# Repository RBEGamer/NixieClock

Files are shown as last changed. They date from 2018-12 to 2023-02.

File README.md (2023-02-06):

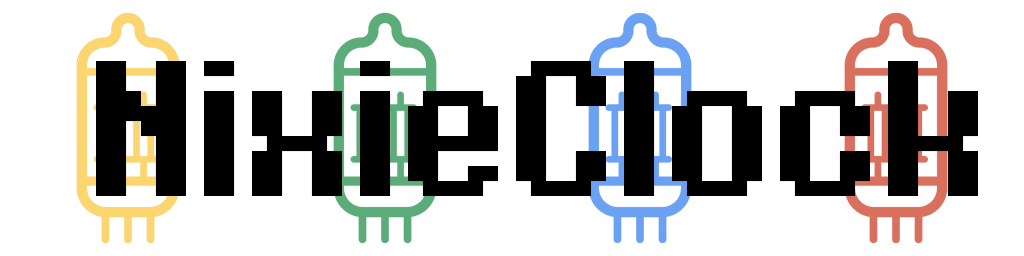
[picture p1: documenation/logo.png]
Gopher image


# A IN-16/IN-8 based nixie clock with WIFI

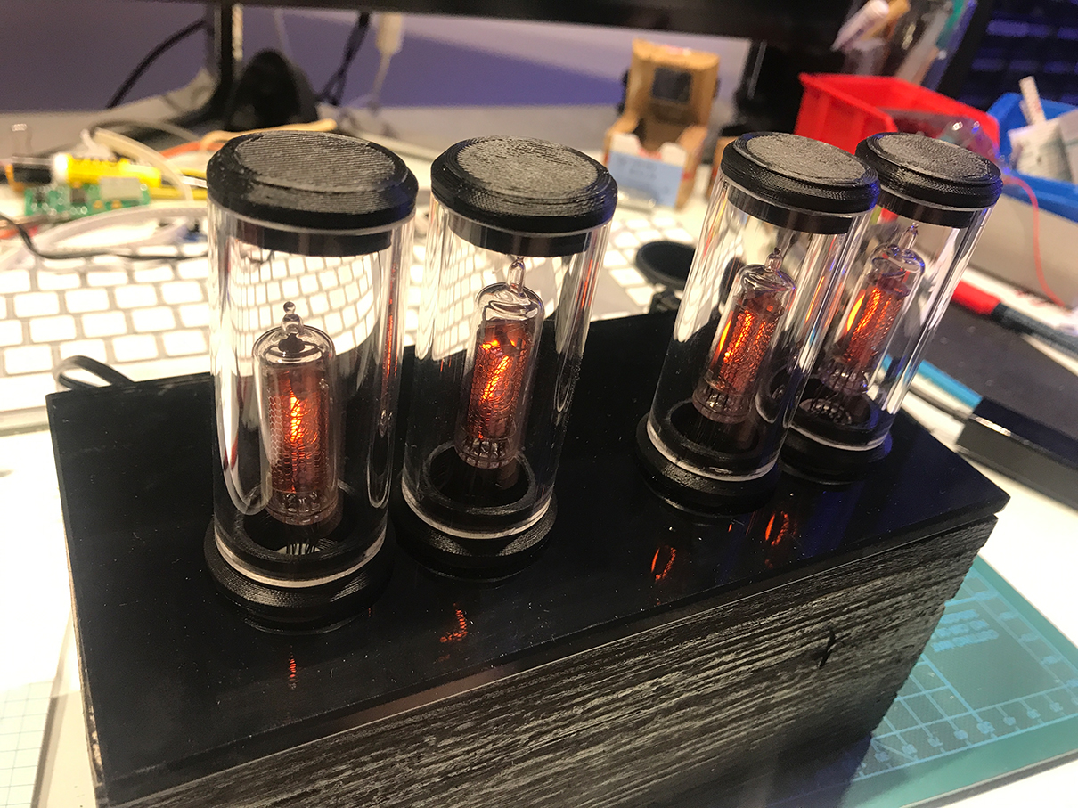
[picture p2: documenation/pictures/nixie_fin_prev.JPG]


# FEATURES
* burn out protection (cycle all numbers for 10 seconds every 10minutes)
* in8 or in16 tube usable via adapter pcbs
* for 4 (hours:mins) or 6 tubes (hours:mins:secs)
* easy to expand
* simple schematic using THT parts only
* tube holders with simple mount for easy replacement

## [OPTIONAL] FEATURES WIFI EXTENTION
* using esp8266 to add wifi support
* NTP SYNC
* CAPTIVE PORTAL to set wifi settings
* set timezone
* start antiburn-in cycle

# PARTS
* 1 control pcb see `./documenation/nixie_clock_controller_gerber.zip`
* 4 Nixie Clock Adapter board for IN8 tube `./nixie_clock_in8_gerber.zip` or IN16 tube `./documenation/nixie_clock_in16_gerber.zip`
* 4 Nixie tubes IN16 or IN8
* 4 nixie tube drivers SN74141
* 1 Arduino Nano
* 1 RTC Module DS1307
* 4 20k resistors 1/2w
* 1 Nixie power supply 180v
* 3 THT push button
* 2 shift registers 75HC595

* 3 5mm led 20ma
* R1 R5 R6 = 10k pull up resistors
* R2 R3 R4 = 330 (for the leds)

* headers male and female

## PARTS WIFI ADDON
(you can wire a nodemcu directly to the rx/tx of the arduino, so no need for a pcb)

* wifi addon pcb
* esp8266 12-e
* lm1117 (e.g. LM1117IMP-3.3/NOPB)
* C1;C2; C3 =  470uf
* R2, R3,R5, R6 =  10k
* R1 = 1k
* R4 = 2k
* 2x 3x1 2.54 headers + 2 jumpers

resistors used for voltage divider for the tx(arduino)->rx(esp8266)

## PARTS FOR SECOND 6-TUBE VERSION
* seconds addon pcb
* 1 75HC595
* 2 Nixie tubes IN16 or IN8
* 2 nixie tube drivers SN74141
* 2 20k resistors 1/2w

# PARTS FOR THE CASE
* 7 wood pieces 10*20cm @ >8mm
* 4 tube cover pipe holder `./documenation/3d_parts/pipe_holder_bottom.stl`
* 4 tube cover pipe covers `./documenation/3d_parts/pipe_holder_top.stl`
* 2 tube pcb mounting brackets `./documenation/3d_parts/tube_pcb_mounting_bracket.stl`
* 2 tube pcb mounting bracket covers`./documenation/3d_parts/tube_pcb_mounting_bracket_covers.stl`
* 4 PCB spacers for M3
* 4 M3 screws 10mm
* 2 M4 screws 16mm
* woodglue
* 2k glue (mounting 3d parts on glass cover)
* hotglue

# TOOLS
* drill 4mm 6mm 20mm(for tubes)
* saw
* soldering iron
* hotgluegun
* step-drill

# PCB
Images, gerber and schematic can be found in the `./documenation` folder.
You also can use a breadboard or a arduino prototyping shield to build the simple schematic.

# CASE

# DRILLING FOUR TUBE VARIANT
For the top wood plate i have made drill drawing where to drill the 20mm holes for the tubes, if you are using the 10x20cm wood plates.
The PDF can be found at `./documenation/nixie_case_drilling_plan.pdf`
The important thing is that one pair of tubes are 35mm away from each other to match with 3d printed mounting brackets.
See the pictures of the build below!

## THE CONTROL PCB
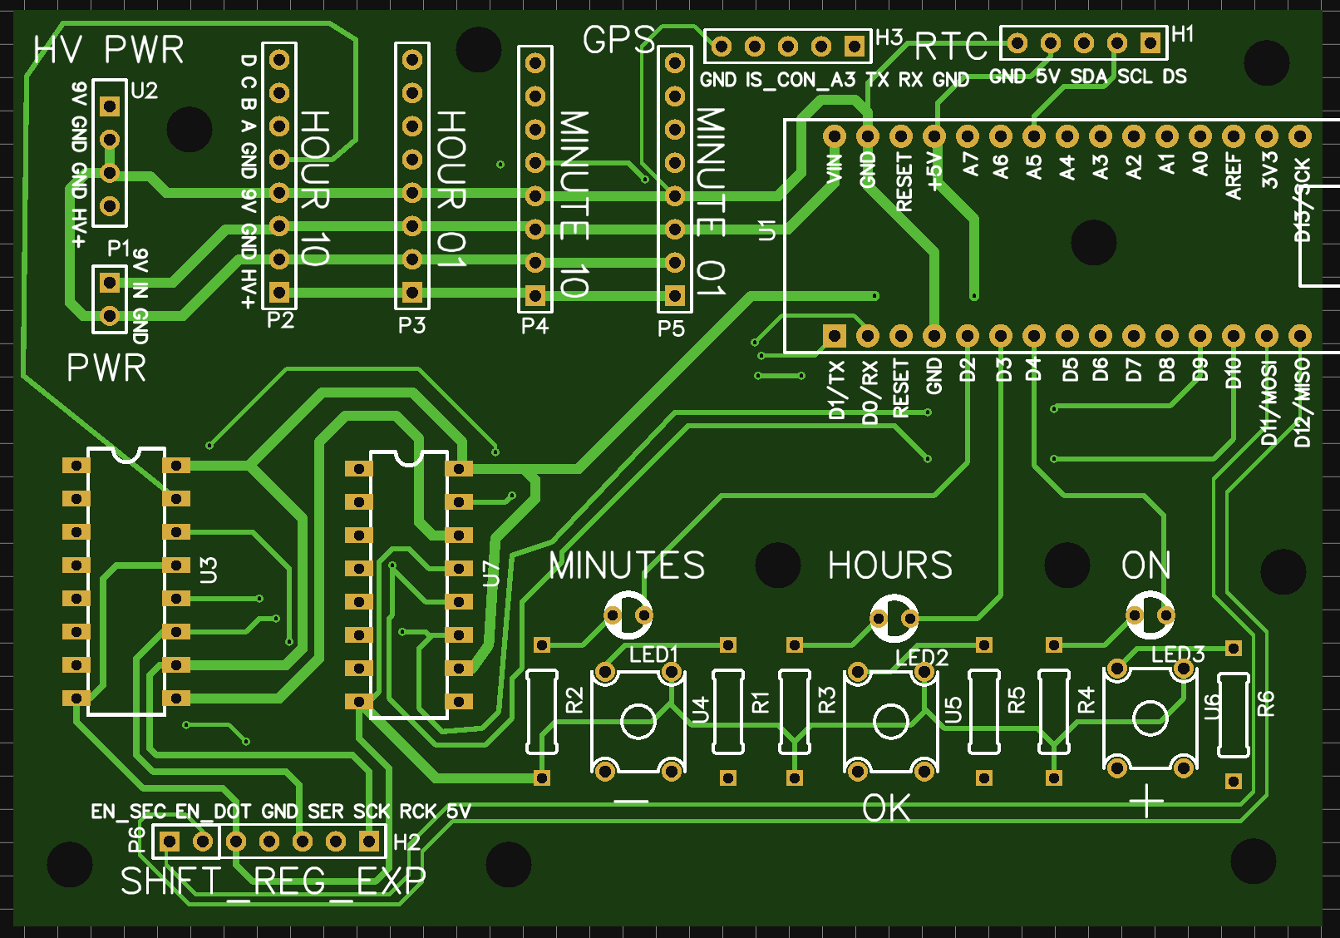
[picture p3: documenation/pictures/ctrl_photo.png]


## NIXIE ADAPTER FOR IN-8 TUBES
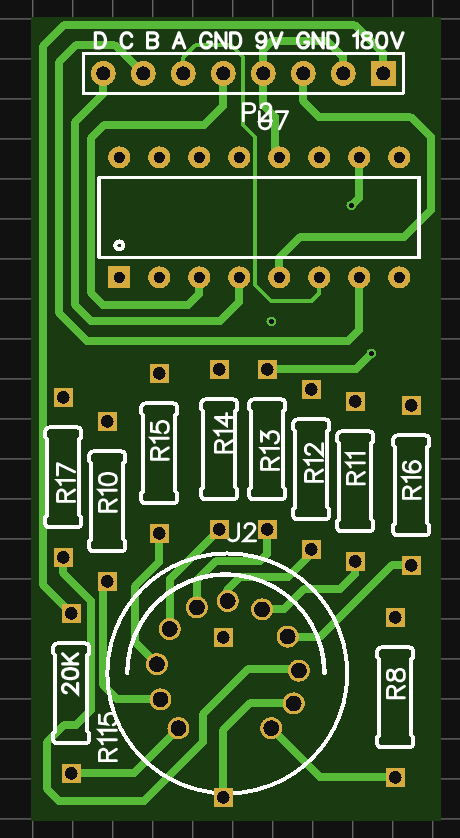
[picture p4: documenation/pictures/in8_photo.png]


You can replace the resistors with wires, except for the `R115 Anode-Current-Resistor 20K`.
The other resitors are for adjust the brightness of each tube segment.

### NOTE
The `SN74141` will be powered from 5V directly from the 5V rail from the Arduino. This works perfectly fine!
Ignore the `9V` marking on the PCB.

## NIXIE ADAPTER FOR IN-16 TUBES [NOT TESTED]
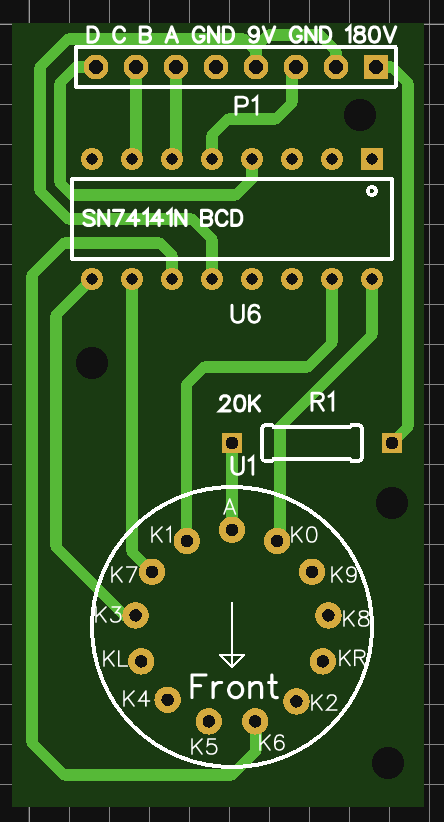
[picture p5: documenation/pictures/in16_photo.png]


## WIFI PCB ADDON

**PLEASE USE THE CORRECT RESISTOR VALUES LISTED IN THE PARTS SECTION**
This wifi addon pcb sits directly under the Arduino Nano, and is soldered to its header pins.
Then this sandwich is plugged into the control pcb. The Arduino-Nano is still required!

### NOTE
To program the `ESP8266`, you have to use a `USB2Serial` cable.
Solder The `RX,TX,GND` pins from the cable to `TX,RX,GND` of the `ESP8266`. 
Remove the two jumpers `EN_UART` from the board!
To reset the `ESP8266` to its flash-mode hold the `BOOT`-Button and toggle the `RESET`-Button. After that, click `Upload` in your Arduino-IDE.
**Use as sketch the `/src/wifi_extention/wifi_extention.ino` for the ESP8266**

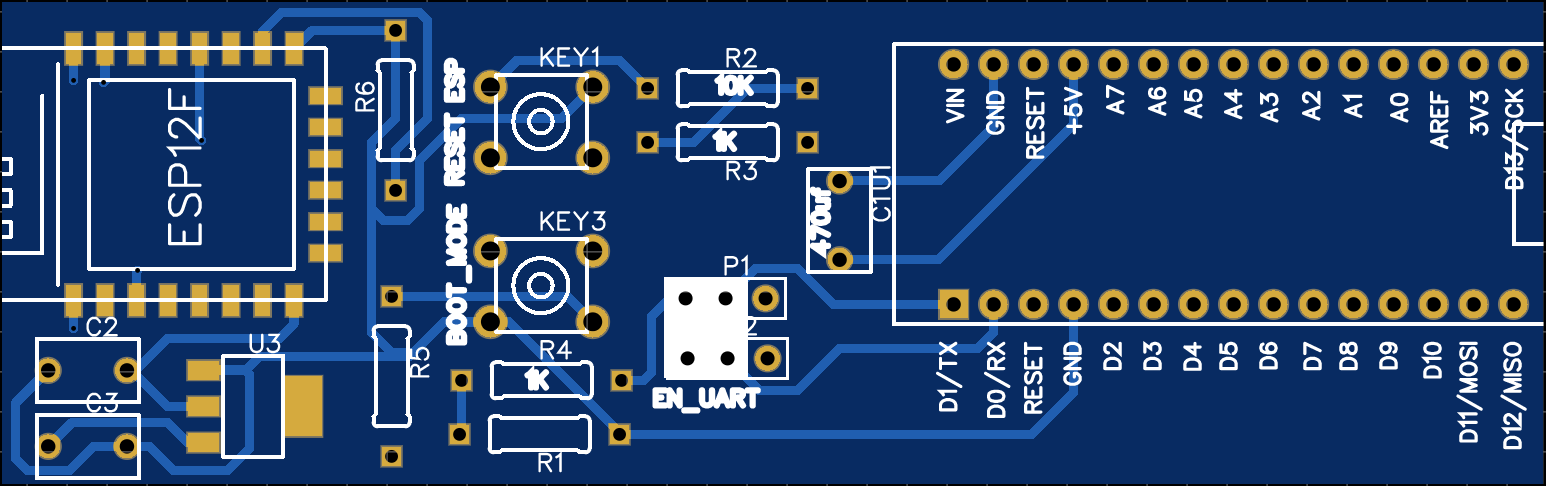
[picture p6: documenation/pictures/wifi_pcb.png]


## SEONDS  ADDON PCB

This pcb add 2 more nixie tube outputs, if you want to have seconds.
No software modification needed. it simply adds an other shift register at the end of the chain.

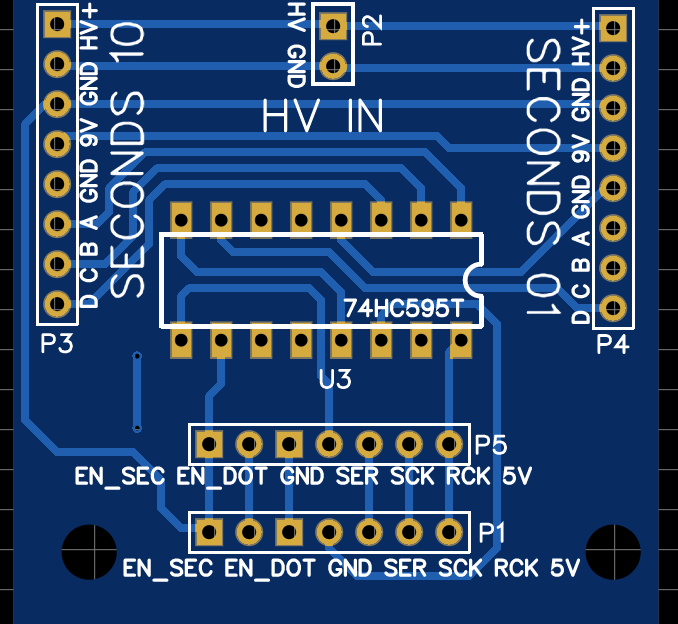
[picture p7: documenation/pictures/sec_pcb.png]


### SOFTWARE
To flash the arduino you can use the Arduino IDE to flash the `./src/nixie_driver/nixie_driver.ino`
Select the Arduino-Nano board and the serial port to upload the program.

### SET TIME
After power up the clock you can use the buttons to change the time.
Select with the `OK-BUTTON` to change between minutes or hours and change them with the `+ / - Buttons`.

### SERIAL COMMANDS
The clock send out the current time string `_t_hours_mins_secs_`.

To set the clock using serial you can use the `st` time command: `_st_hours_mins_`

**Note: The `_` at the end has to be send, with the `\n` new line charater. **

# PICTURES

## SIMPLE BOX
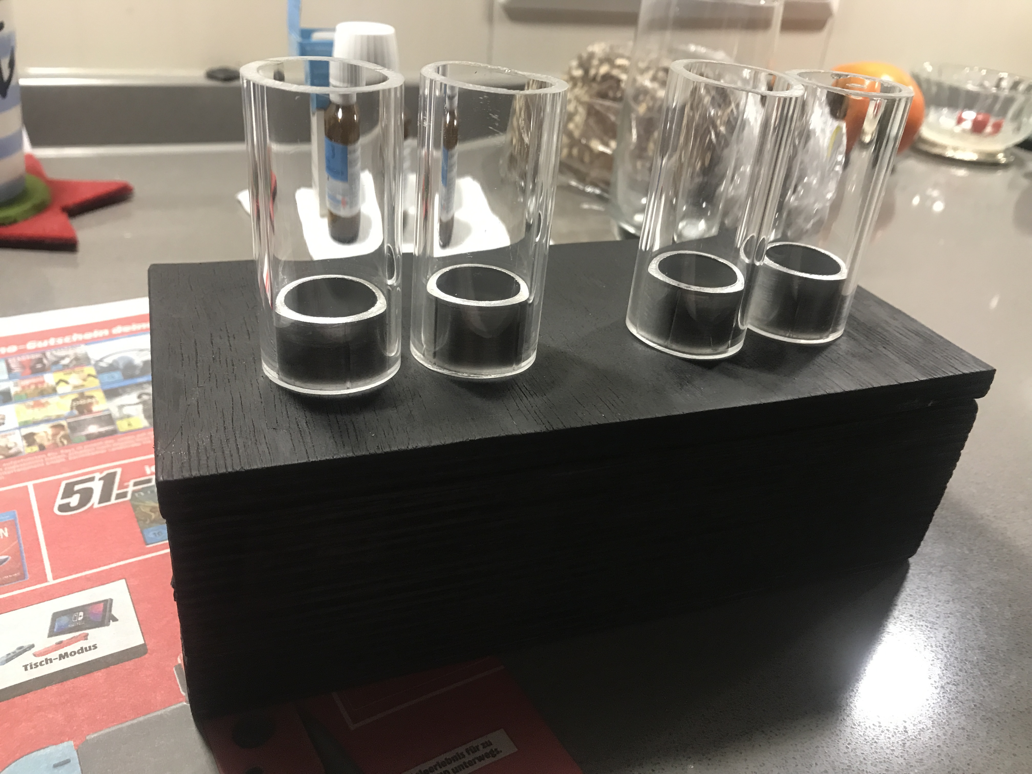
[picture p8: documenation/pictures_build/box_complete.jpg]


## PCB TEST 1
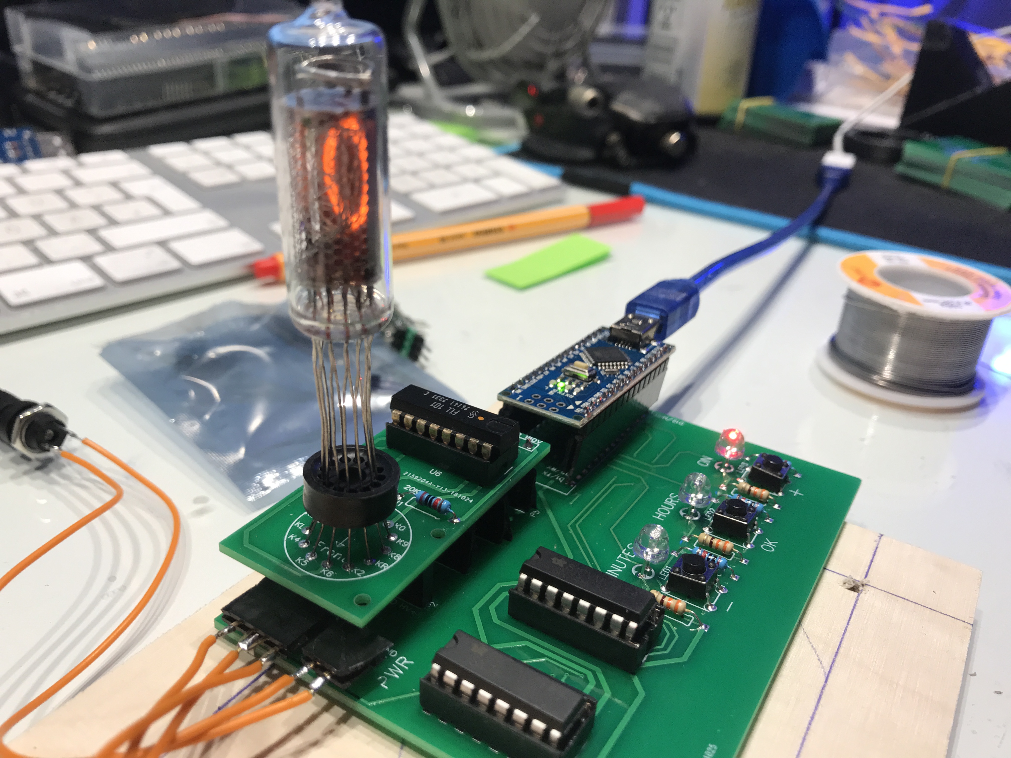
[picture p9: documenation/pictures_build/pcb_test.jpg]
test image size


## PCB TEST 2
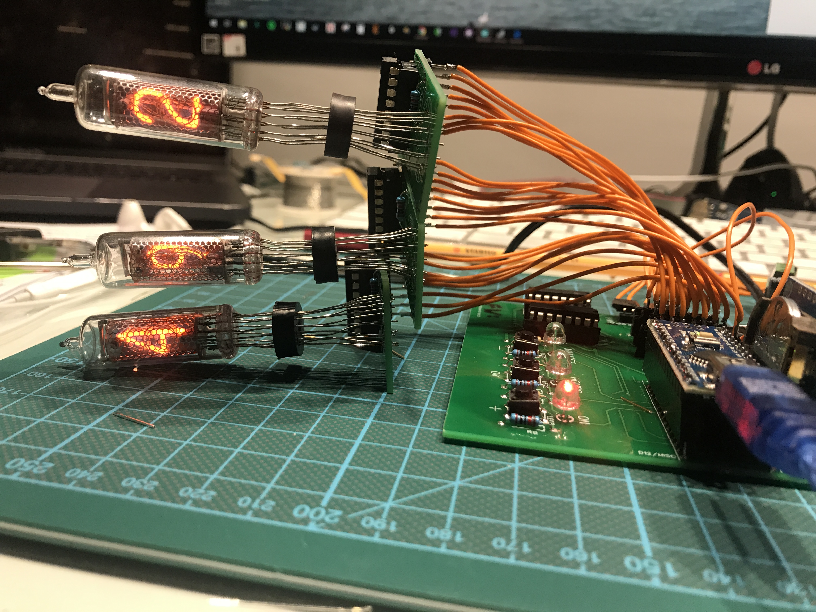
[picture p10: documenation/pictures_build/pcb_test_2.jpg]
test image size


## TUBE MOUNT 1
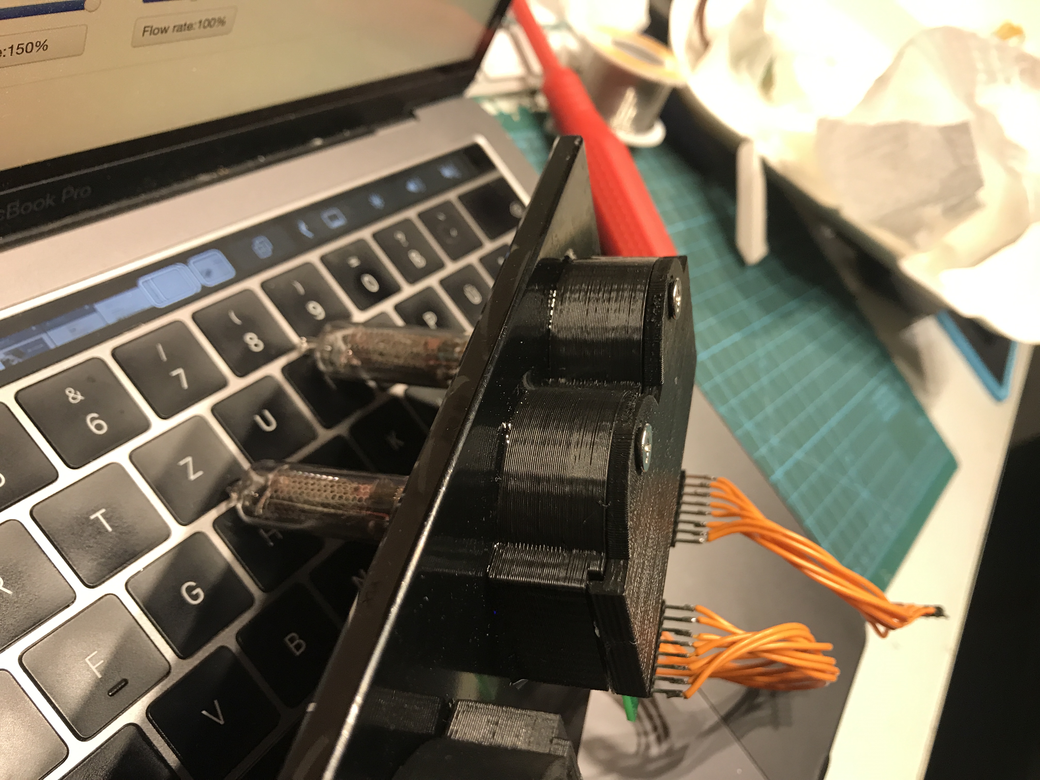
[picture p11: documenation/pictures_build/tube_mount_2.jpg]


## TUBE MOUNT 2
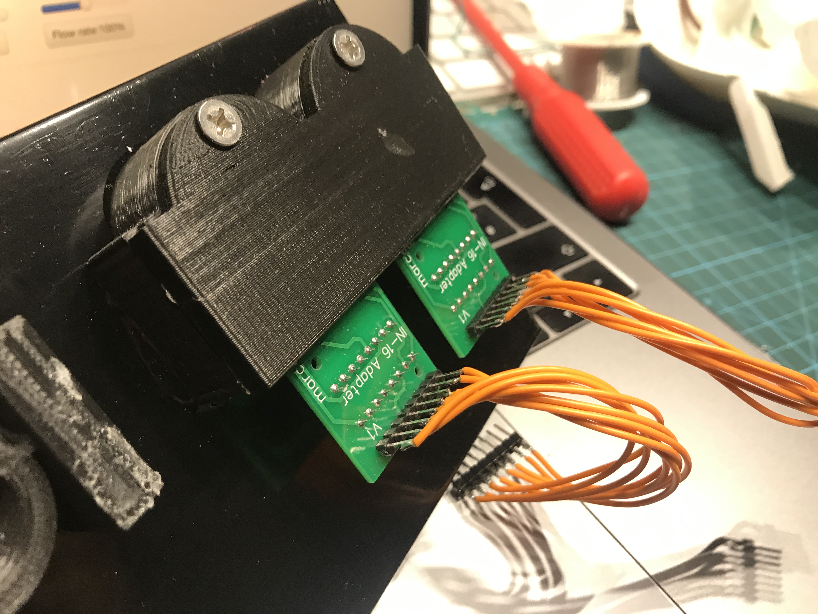
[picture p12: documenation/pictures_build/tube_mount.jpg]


## WIFI MODULE

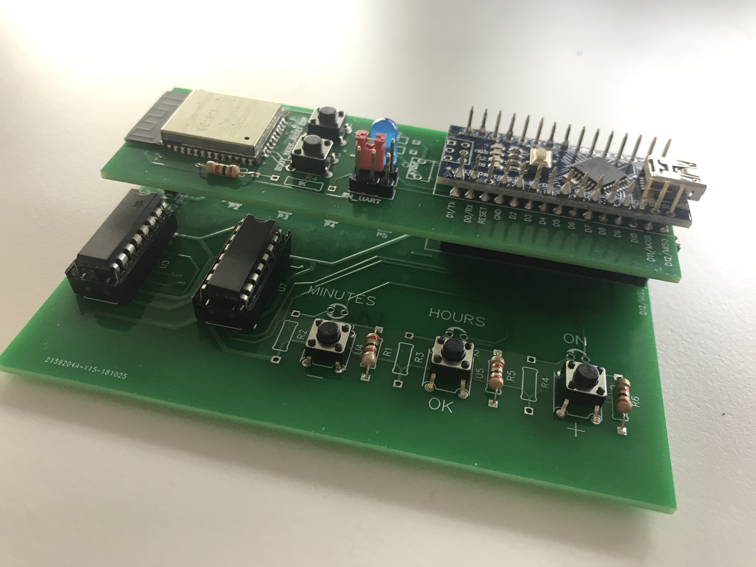
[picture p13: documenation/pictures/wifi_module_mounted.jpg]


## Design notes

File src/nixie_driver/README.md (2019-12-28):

# Arduino Firmware

The software for the arduino nano can be found here. Use the `nixie_driver.ino` to flash your arduino on the control pcb.

## PLEASE DONT USE `__nixie_driver_fix_for_clock_model_1.ino__`

This software verison is for my personal experimental nixie clock, where i can play with other hardware

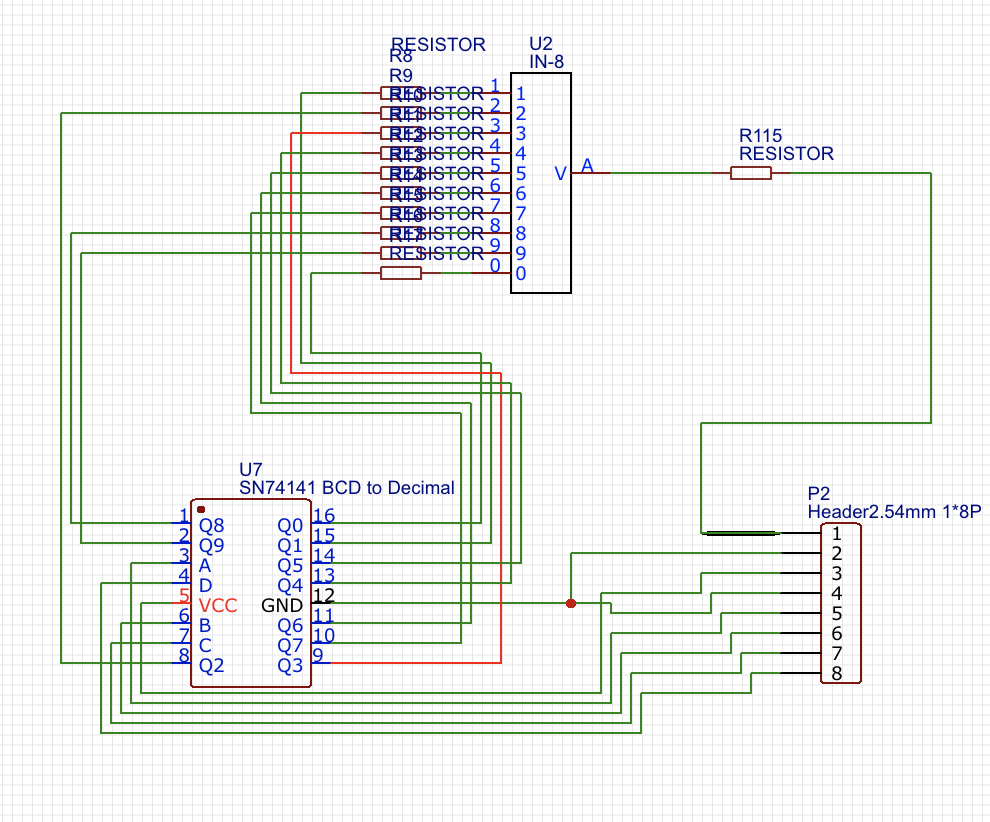
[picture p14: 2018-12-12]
documenation/pictures/in8_schem.png

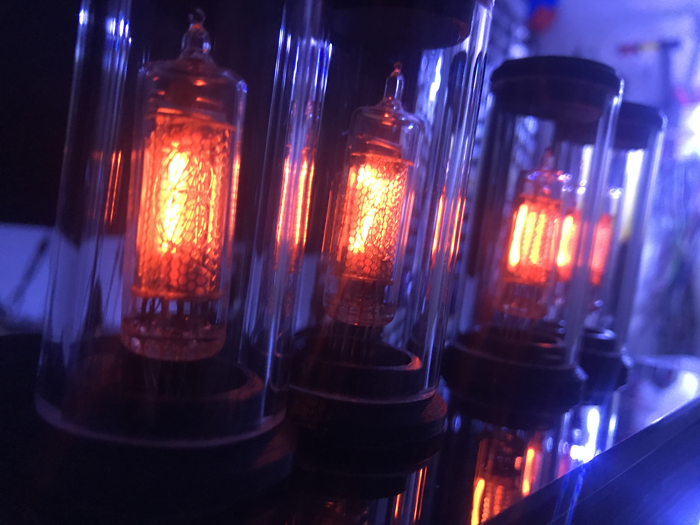
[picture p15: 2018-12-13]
documenation/pictures/nixie_fin_4.JPG

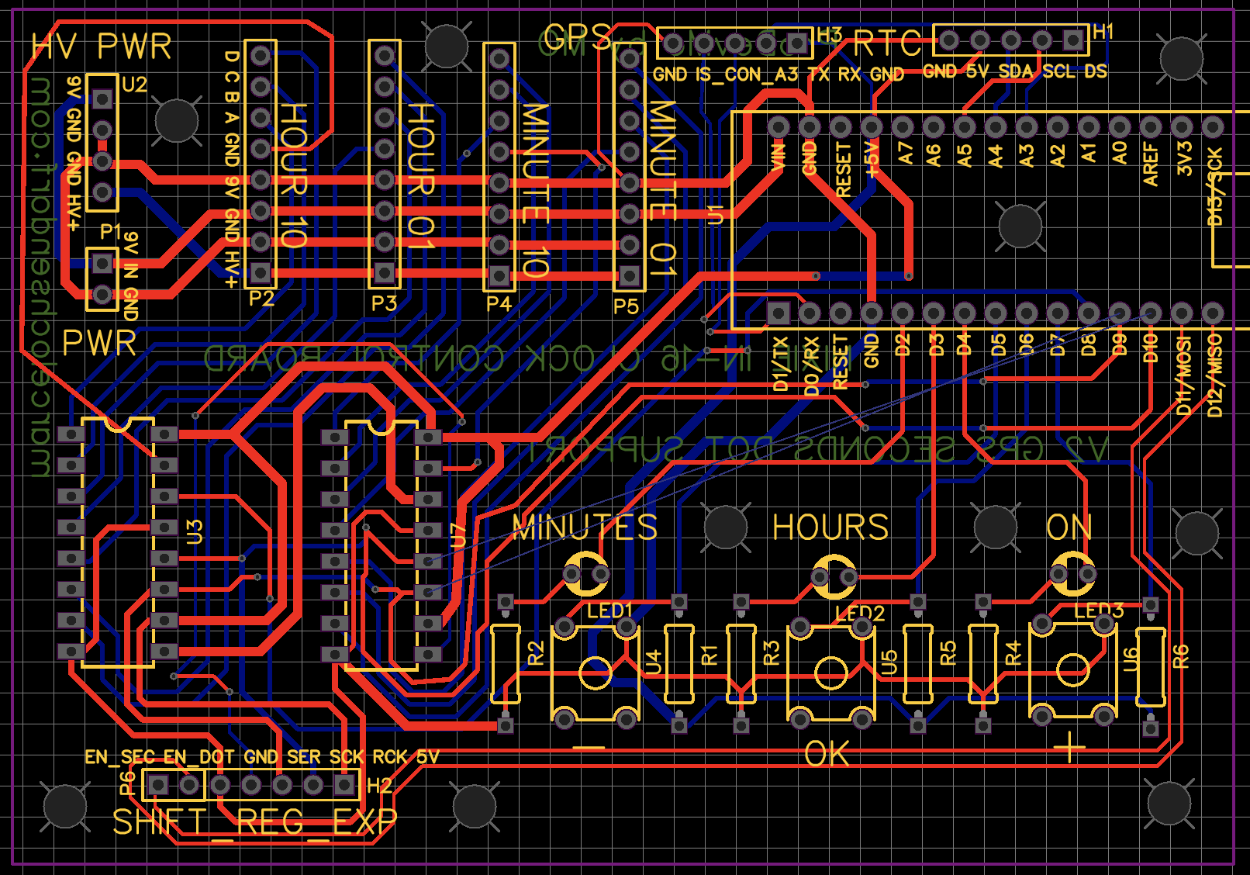
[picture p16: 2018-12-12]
documenation/pictures/crtl_pcb.png

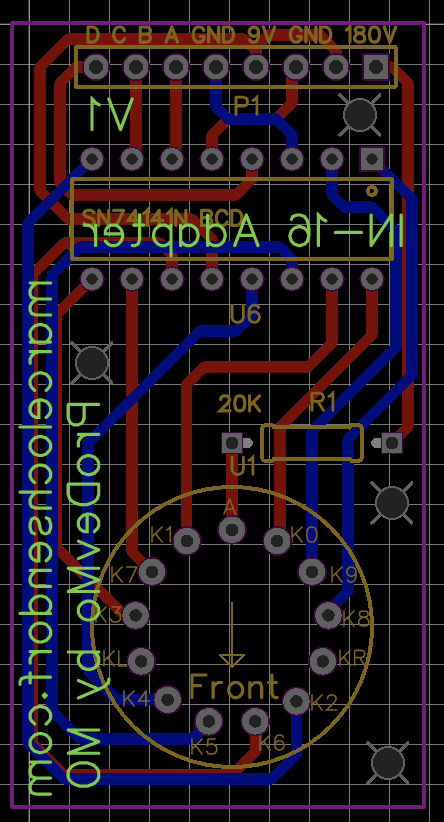
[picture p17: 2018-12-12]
documenation/pictures/in16_pcb.png

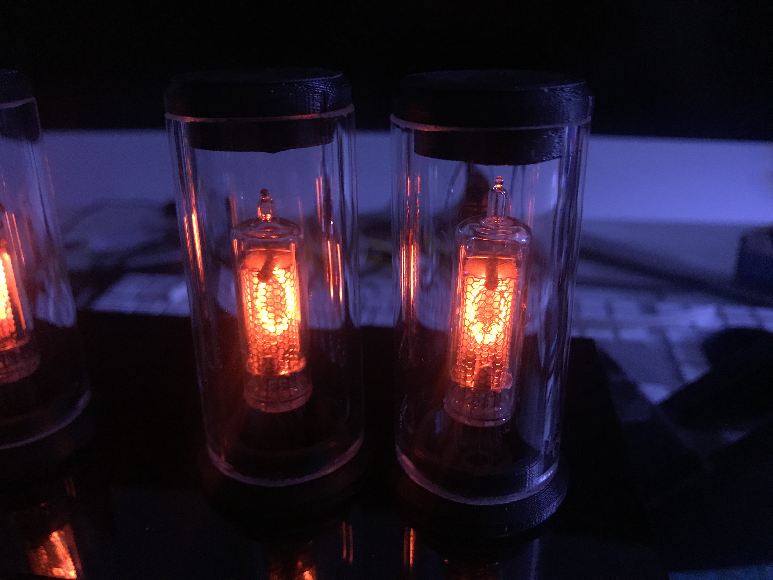
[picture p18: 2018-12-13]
documenation/pictures/nixie_fin_5.JPG

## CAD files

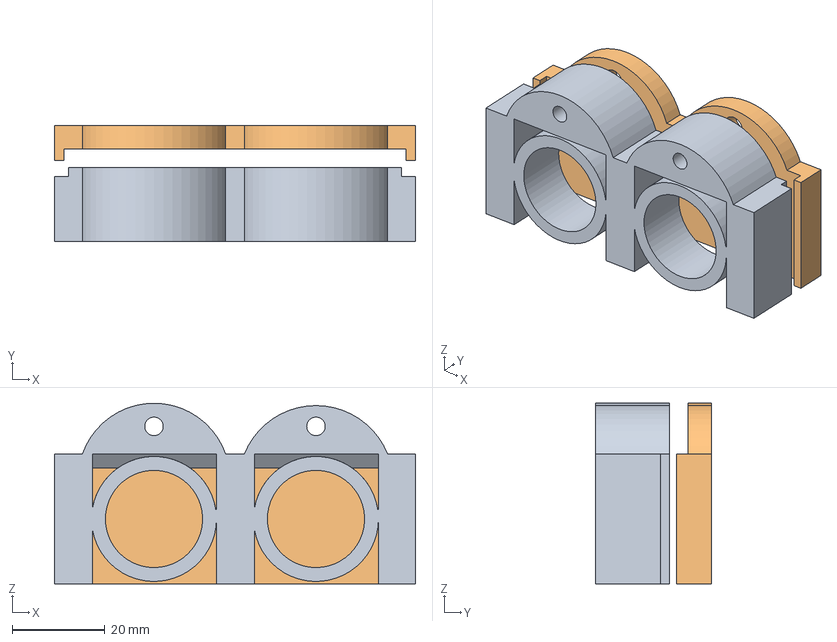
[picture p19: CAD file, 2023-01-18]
documenation/3d_parts/nixie_holder v9.step
78.0 x 25.0 x 39.0 mm

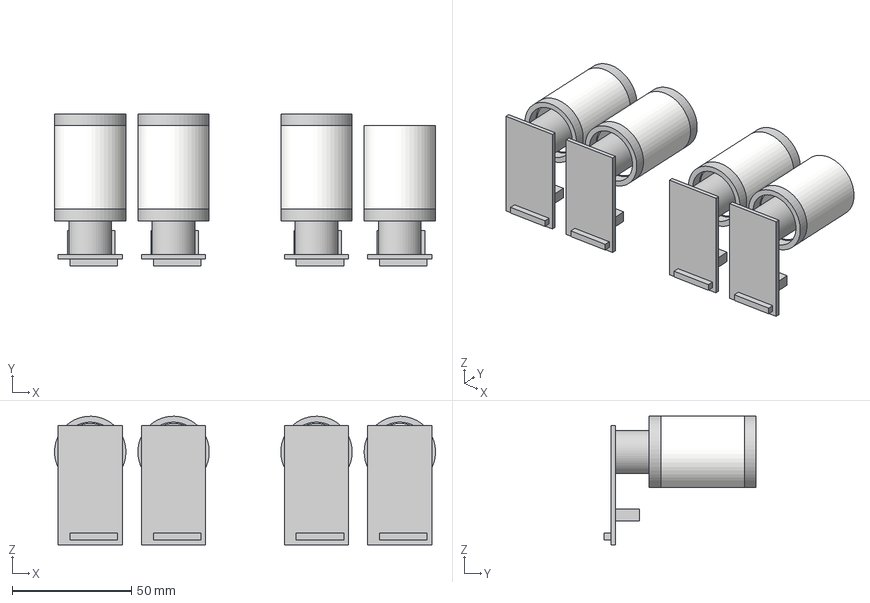
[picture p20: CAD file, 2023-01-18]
documenation/3d_parts/nixie-case v8.step
160.0 x 64.0 x 54.0 mm
nixie_modul x 4
alu_ring x 4
plexi x 4
alu_top x 3

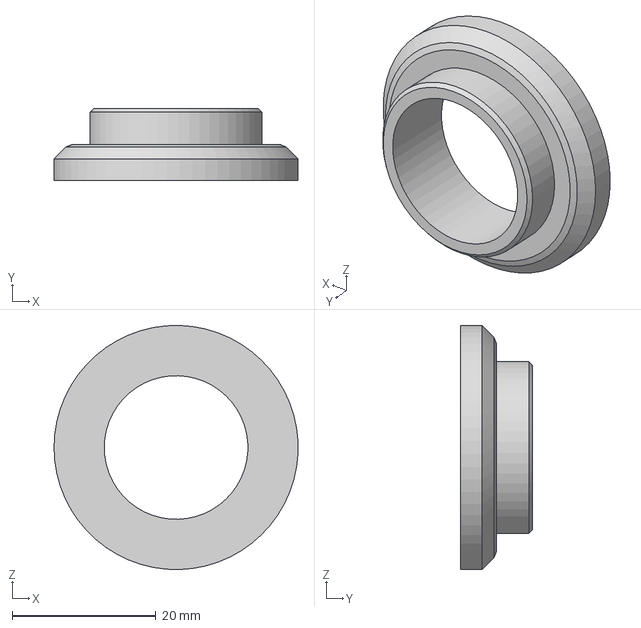
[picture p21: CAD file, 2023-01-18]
documenation/3d_parts/nixie_rohr_mount_24x30 v4.step
34.0 x 10.0 x 34.0 mm

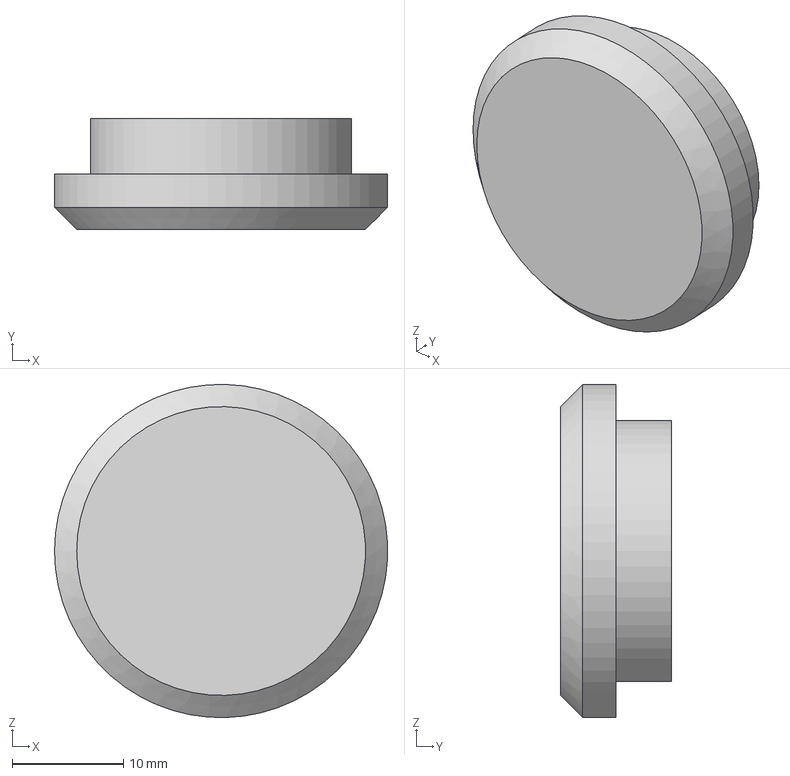
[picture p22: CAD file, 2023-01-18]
documenation/3d_parts/nixie_rohr_abdeckung_24x30 v2.step
30.0 x 10.0 x 30.0 mm

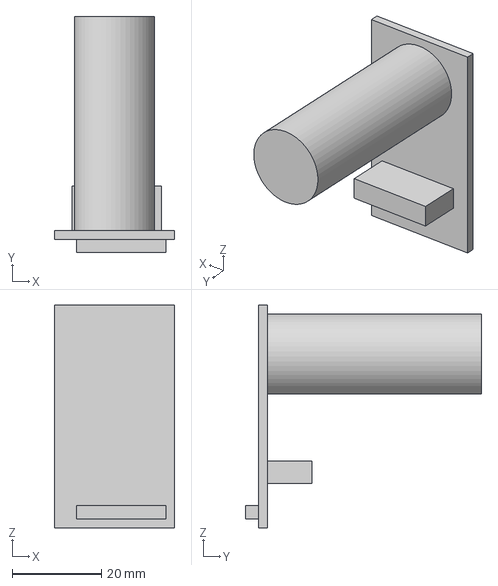
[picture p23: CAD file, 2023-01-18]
documenation/3d_parts/nixie_adapter v2.step
27.0 x 53.0 x 50.0 mm

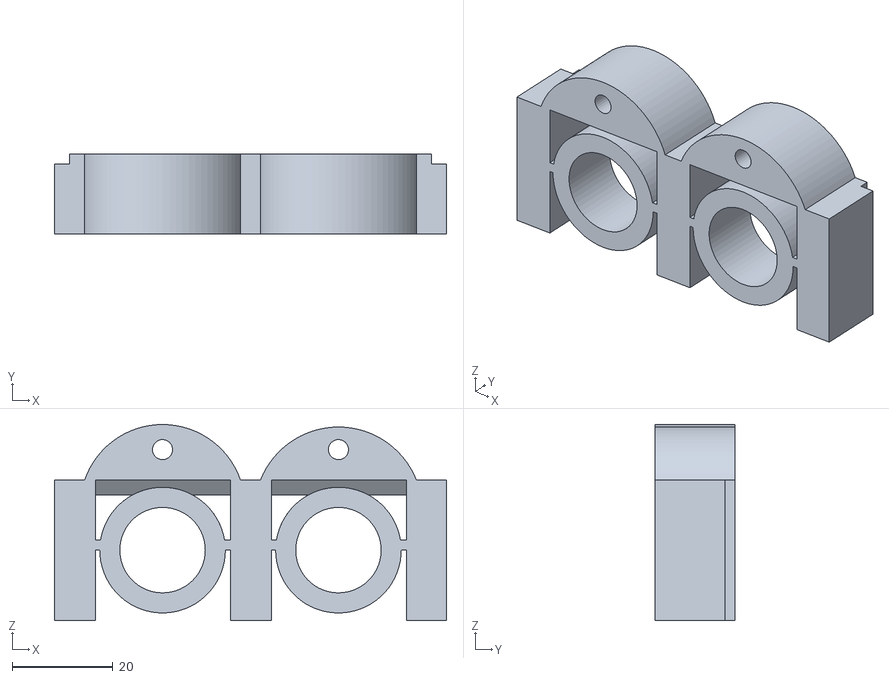
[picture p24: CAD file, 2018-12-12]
documenation/3d_parts/tube_pcb_mounting_bracket.stl
78.0 x 16.0 x 39.0

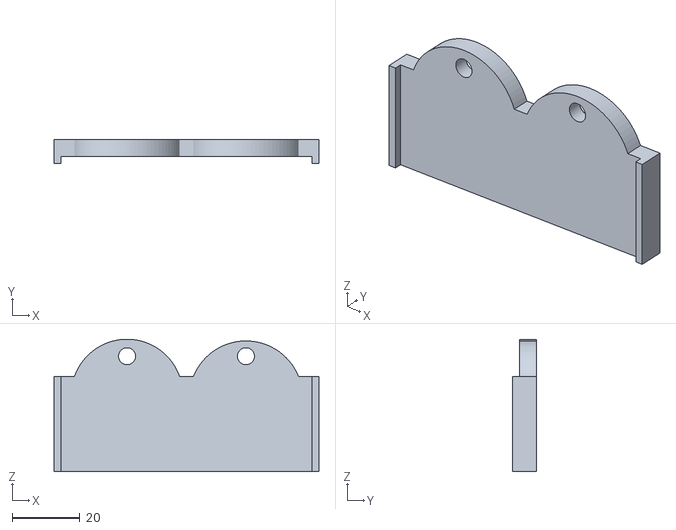
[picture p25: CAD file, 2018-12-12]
documenation/3d_parts/tube_pcb_mounting_bracket_cover.stl
78.0 x 7.00 x 39.0

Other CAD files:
documenation/3d_parts/pipe_holder_bottom.stl
documenation/3d_parts/pipe_holder_top.stl
documenation/3d_parts/nixie_adapter v2.f3d
documenation/3d_parts/nixie_holder v9.f3d
documenation/3d_parts/nixie_rohr_abdeckung_24x30 v2.f3d
documenation/3d_parts/nixie_rohr_mount_24x30 v4.f3d

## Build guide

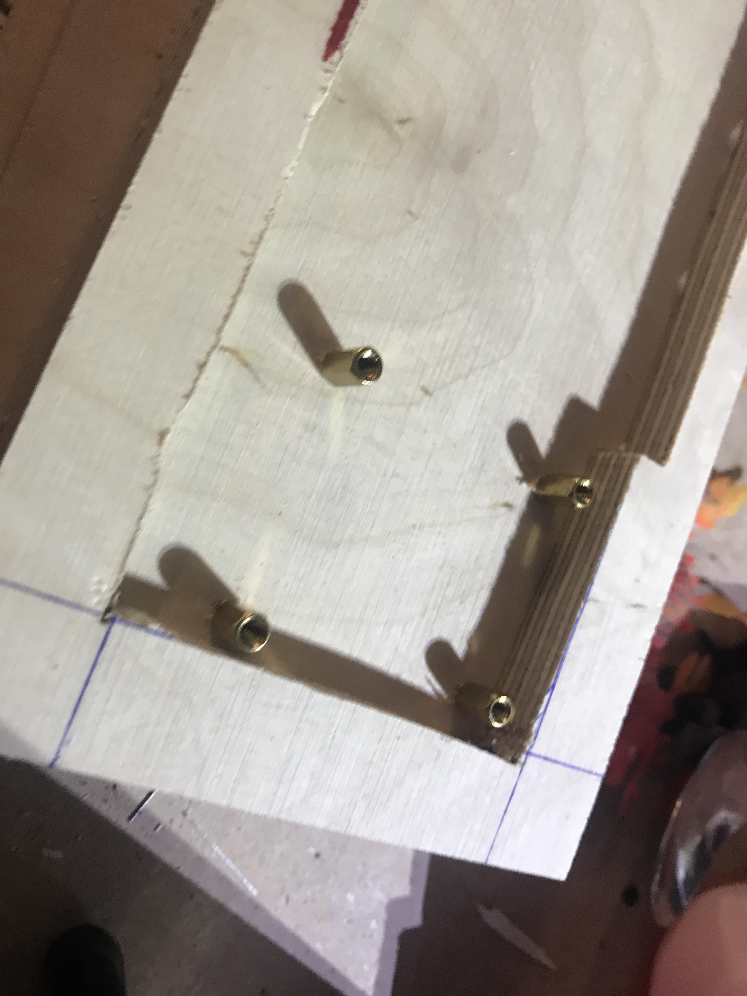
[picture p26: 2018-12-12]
documenation/pictures_build/2018-11-07 23.21.06.jpg

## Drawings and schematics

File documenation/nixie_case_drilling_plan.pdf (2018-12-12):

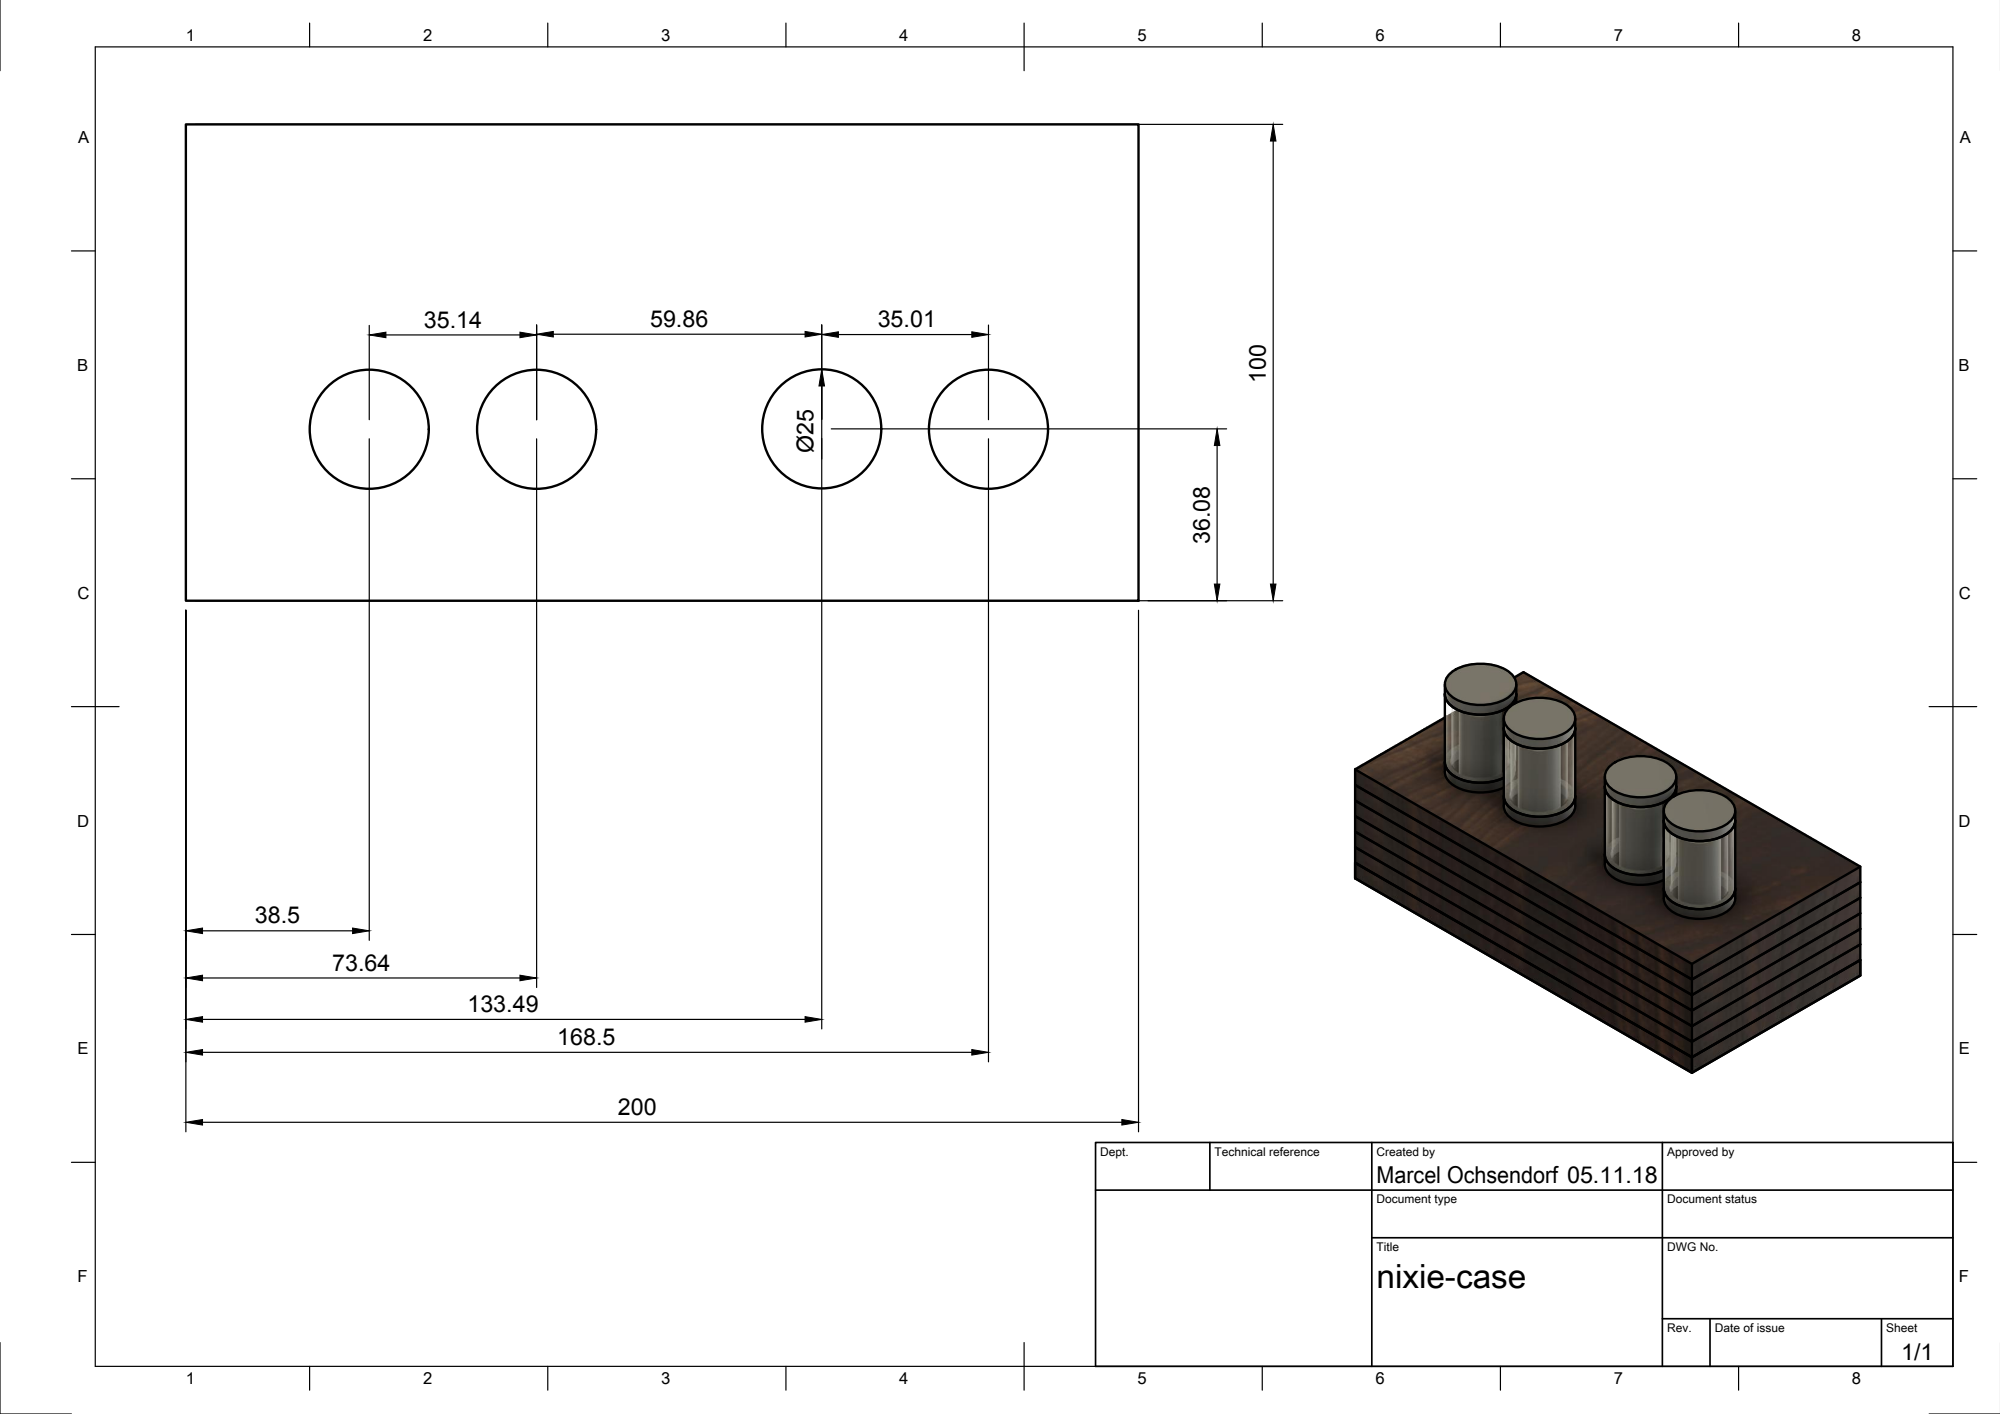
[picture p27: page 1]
Marcel Ochsendorf 36.08 Ø25

Dept. | Technical reference | Created by 05.11.18 | Approved by

Document type | Document status

Title nixie-case | DWG No.

Rev. | Date of issue | Sheet 1/1

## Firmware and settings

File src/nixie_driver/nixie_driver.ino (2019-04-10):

const int shiftPin = 9; //SH_CP
const int storePin = 10;//ST_CP
int dataPin = 8; //DS

#define NIXIE_UPDATE_INTERVAL_SECONDS 1
#define NIXIE_SECOND_DISPLAY_I2C_ADDR 8
int led_min_pin = 2;
int led_hour_pin = 3;
int led_on_pin = 4;

int sw_add_pin = 7;
int sw_sub_pin = 5;
int sw_ok_pin = 6;

int random_timer = 0;
int mode = 0; //0 =min 1==hour 2=on

#include <Wire.h>

#include "RTClib.h"


RTC_DS1307 rtc;
int hours = 0;
int mins = 0;
int secs = 0;
unsigned long time;

unsigned long BCDencode(unsigned long binval) {
  unsigned long bcdval = 0;
  for (int i = 0; binval && i < sizeof(bcdval) * 8; i += 4) {
    bcdval += (binval % 10) << i;
    binval /= 10;
  }
  return bcdval;
}

String readString;
String getValue(String data, char separator, int index) {
  int found = 0;
  int strIndex[] = {
    0,
    -1
  };
  int maxIndex = data.length() - 1;
  for (int i = 0; i <= maxIndex && found <= index; i++) {
    if (data.charAt(i) == separator || i == maxIndex) {
      found++;
      strIndex[0] = strIndex[1] + 1;
      strIndex[1] = (i == maxIndex) ? i + 1 : i;
    }
  }
  return found > index ? data.substring(strIndex[0], strIndex[1]) : "";
}

void setup() {

  Serial.begin(9600);

   Wire.begin();
  delay(500);
  pinMode(storePin, OUTPUT);
  pinMode(shiftPin, OUTPUT);
  pinMode(dataPin, OUTPUT);
  pinMode(sw_add_pin, INPUT);
  pinMode(sw_sub_pin, INPUT);
  pinMode(sw_ok_pin, INPUT);

  pinMode(led_on_pin, OUTPUT);
  digitalWrite(led_on_pin, LOW);
  pinMode(led_min_pin, OUTPUT);
  digitalWrite(led_min_pin, LOW);
  pinMode(led_hour_pin, OUTPUT);
  digitalWrite(led_hour_pin, LOW);
  mode = 2;

  random_timer = 0;

  if (!rtc.begin()) {
    for (int i = 0; i < 4; i++) {
      delay(100);
      digitalWrite(led_hour_pin, HIGH);
      delay(100);
      digitalWrite(led_hour_pin, LOW);
    }
    Serial.println("_rct_begin_error_");
  }

  if (!rtc.isrunning()) {
    for (int i = 0; i < 4; i++) {
      delay(100);
      digitalWrite(led_min_pin, HIGH);
      delay(100);
      digitalWrite(led_min_pin, LOW);
    }
    //  Serial.println("RTC is NOT running!");
    rtc.adjust(DateTime(F(__DATE__), F(__TIME__)));
    Serial.println("_rct_isrunning_error_");
  }

  delay(100);
  DateTime now = rtc.now();
  hours = now.hour();
  mins = now.minute();
  secs = now.second();
  time = millis();
  delay(100);
  anti_burn_out();
}


//#define FIX
const int shift_digits = 24;
void update_nixie() {
  #ifdef FIX
  unsigned long t = BCDencode(hours);
  unsigned long s = BCDencode(mins);
  unsigned long r = BCDencode(secs);
  #else
  unsigned long r = BCDencode(hours);
  unsigned long s = BCDencode(mins);
  unsigned long t = BCDencode(secs);
  #endif
  


  Wire.beginTransmission(NIXIE_SECOND_DISPLAY_I2C_ADDR); // transmit to device #8
  Wire.write((int)secs);              // sends one byte
  Wire.endTransmission();    // stop transmitting


  //BlINK DOTS
  unsigned long tsdot = 0;
  if ((secs % 2) == 0) {
    tsdot = 1;
  }

  int muster[shift_digits + 1] = {
    tsdot & 1,
    t & 8,
    t & 4,
    t & 2,
    t & 1,
    t & 128,
    t & 64,
    t & 32,
    t & 16,
    s & 8,
    s & 4,
    s & 2,
    s & 1,
    s & 128,
    s & 64,
    s & 32,
    s & 16,
    r & 8,
    r & 4,
    r & 2,
    r & 1,
    r & 128,
    r & 64,
    r & 32,
    r & 16
  };
  digitalWrite(storePin, LOW);
  for (int i = 0; i < shift_digits + 1; i++) {
    digitalWrite(shiftPin, LOW);
    digitalWrite(dataPin, muster[i]);
    digitalWrite(shiftPin, HIGH);
  }
  digitalWrite(storePin, HIGH);

  Serial.print("_t_");
  Serial.print(hours);
  Serial.print("_");
  Serial.print(mins);
  Serial.print("_");
  Serial.print(secs);
  Serial.println("_");

}

void update_rtc() {
  rtc.adjust(DateTime(2000, 1, 1, hours, mins, 0));
  Serial.print("_t_");
  Serial.print(hours);
  Serial.print("_");
  Serial.print(mins);
  Serial.print("_");
  Serial.print(secs);
  Serial.println("_");

}

void anti_burn_out() {
  Serial.println("_abi_begin_");

  for (int j = 0; j < 4; j++) {
    for (int i = 0; i < 10; i++) {
      Wire.beginTransmission(NIXIE_SECOND_DISPLAY_I2C_ADDR); // transmit to device #8
      Wire.write((int)i*11);              // sends one byte
      Wire.endTransmission();
  
      int muster[shift_digits] = {
        i & 8,
        i & 4,
        i & 2,
        i & 1,
        i & 8,
        i & 4,
        i & 2,
        i & 1,
        i & 8,
        i & 4,
        i & 2,
        i & 1,
        i & 8,
        i & 4,
        i & 2,
        i & 1,
        i & 8,
        i & 4,
        i & 2,
        i & 1,
        i & 8,
        i & 4,
        i & 2,
        i & 1
      };
      digitalWrite(storePin, LOW);
      for (int i = 0; i < shift_digits; i++) {
        digitalWrite(shiftPin, LOW);
        digitalWrite(dataPin, muster[i]);
        digitalWrite(shiftPin, HIGH);
      }
      digitalWrite(storePin, HIGH);
      delay(1000);
    }
    update_nixie();
  }
  Serial.println("_abi_finished_");
}

void loop() {
    // Hier passiert nichts.
    DateTime now = rtc.now();
    hours = now.hour();
    mins = now.minute();
    secs = now.second();
 

  while (Serial.available()) {
    delay(30); //delay to allow buffer to fill
    if (Serial.available() > 0) {
      char c = Serial.read(); //gets one byte from serial buffer
      readString += c; //makes the string readString
      if (c == '\n') {
        Serial.flush();
        break;
      }
    }
  }

if (readString.length() > 0) {

  if (getValue(readString, '_', 1) == "st") {

    int tmp_hours = getValue(readString, '_', 2).toInt();
    int tmp_mins = getValue(readString, '_', 3).toInt();

    if (tmp_hours > 0 && tmp_hours < 24 && tmp_mins > 0 && tmp_mins < 60) {
      hours = tmp_hours;
      mins = tmp_mins;
      update_rtc();
    } else {
      Serial.println("_error_params.out.of.range_");
    }

  } else if (getValue(readString, '_', 1) == "abi") {
    anti_burn_out();
  }
  readString = "";
}

if (digitalRead(sw_ok_pin) == LOW) {
  delay(50);
  while (digitalRead(sw_ok_pin) == LOW) {
    delay(50);
  }
  Serial.println("_btn_ok_");

}

//TODO ADD SUB
if (digitalRead(sw_add_pin) == LOW) {
  delay(300);
  mins++;
  if (mins > 59) {
    mins = 0;
  }
  update_rtc();
  update_nixie();
  return;
}

if (digitalRead(sw_sub_pin) == LOW) {
  delay(300);
  hours++;
  if (hours > 23) {
    hours = 0;
  }
  update_rtc();
  update_nixie();
  return;
}

if (digitalRead(sw_sub_pin) == LOW && mode == 1) {
  delay(300);
  hours--;
  if (hours < 0) {
    hours = 23;
  }
  update_rtc();
  update_nixie();
  return;
}

//UPDATE THE NIXIE REGIERS EVERY X SEOCND
if ((millis() - time) > (1000 * NIXIE_UPDATE_INTERVAL_SECONDS)) {
  time = millis();
  update_nixie();
  random_timer++;
  if (random_timer > (60 * 10)) {
    random_timer = 0;
    anti_burn_out();
  }
}

//EINBRENNEN VERHINDERN

}

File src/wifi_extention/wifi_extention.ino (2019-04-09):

#define VERSION "0.9"

#include <ESP8266WiFi.h>
#include <WiFiClient.h>
#include <ESP8266WebServer.h>
#include <ESP8266HTTPClient.h>
#include <ESP8266mDNS.h>
#include <WiFiUdp.h>
#include <Wire.h>
#include <FS.h> //Include File System Headers
#include <TimeLib.h>
#include <NTPClient.h>
#include <WiFiManager.h>
#include <WiFiUdp.h>
#include <ArduinoOTA.h>

String time_last = "not synced";
// CONFIG -------------------------------------
#define WEBSERVER_PORT 80 // set the port for the webserver eg 80 8080
#define MDNS_NAME "nixieclock" // set hostname
#define WEBSITE_TITLE "Nixie Clck Confuguration" // name your device
#define SERIAL_BAUD_RATE 9600
#define NTP_SEND_TIME_INTERVAL 10 //sende zeit an uhr all x minuten

#define DEFAULT_NTP_SERVER "pool.ntp.org"
#define DEFAULT_TIMEZONE 1

// END CONFIG ---------------------------------

//FILES FOR STORiNG CONFIGURATION DATA
const char* file_ntp_server = "/file.txt";
const char* file_timezone = "/timezone.txt";
const char* file_syncmode = "/syncmode.txt";


//VARS
int sync_mode = 0;
int timezone = 0;
String ntp_server_url = "";
long long last = 0;
//NTPSyncEvent_t ntpEvent; // Last triggered event

ESP8266WebServer server(WEBSERVER_PORT);

WiFiUDP ntpUDP;
NTPClient timeClient(ntpUDP,DEFAULT_NTP_SERVER,0,60000);



const String phead_1 = "<!DOCTYPE html><html><head><title>";
const String phead_2 = "</title>"
                       "<meta http-equiv='content-type' content='text/html; charset=utf-8'>"
                       "<meta charset='utf-8'>"
                       "<link "
                       "href='http://ajax.googleapis.com/ajax/libs/jqueryui/1.8.16/themes/base/"
                       "jquery-ui.css' rel=stylesheet />"
                       "<script "
                       "src='http://ajax.googleapis.com/ajax/libs/jquery/1.6.4/jquery.min.js'></"
                       "script>"
                       "<script "
                       "src='http://ajax.googleapis.com/ajax/libs/jqueryui/1.8.16/"
                       "jquery-ui.min.js'></script>"
                       "<style>"
                       "html, body {"
                       "  background: #F2F2F2;"
                       " width: 100%;"
                       " height: 100%;"
                       " margin: 0px;"
                       " padding: 0px;"
                       " font-family: 'Verdana';"
                       " font-size: 16px;"
                       " color: #404040;"
                       " }"
                       "img {"
                       " border: 0px;"
                       "}"
                       "span.title {"
                       " display: block;"
                       " color: #000000;"
                       " font-size: 30px;"
                       "}"
                       "span.subtitle {"
                       " display: block;"
                       " color: #000000;"
                       " font-size: 20px;"
                       "}"
                       ".sidebar {"
                       " background: #FFFFFF;"
                       " width: 250px;"
                       " min-height: 100%;"
                       " height: 100%;"
                       " height: auto;"
                       " position: fixed;"
                       " top: 0px;"
                       " left: 0px;"
                       " border-right: 1px solid #D8D8D8;"
                       "}"
                       ".logo {"
                       " padding: 25px;"
                       " text-align: center;"
                       " border-bottom: 1px solid #D8D8D8;"
                       "}"
                       ".menu {"
                       " padding: 25px 0px 25px 0px;"
                       " border-bottom: 1px solid #D8D8D8;"
                       "}"
                       ".menu a {"
                       " padding: 15px 25px 15px 25px;"
                       " display: block;"
                       " color: #000000;"
                       " text-decoration: none;"
                       " transition: all 0.25s;"
                       "}"
                       ".menu a:hover {"
                       " background: #0088CC;"
                       " color: #FFFFFF;"
                       "}"
                       ".right {"
                       " margin-left: 250px;"
                       " padding: 50px;"
                       "}"
                       ".content {"
                       " background: #FFFFFF;"
                       " padding: 25px;"
                       " border-radius: 5px;"
                       " border: 1px solid #D8D8D8;"
                       "}"
                       "</style>";

const String pstart = "</head>"
                      "<body style='font-size:62.5%;'>"
                      "<div class='sidebar'>"
                      "<div class='logo'>"
                      "<span class='title'>NixieCLock</span>"
                      "<span class='subtitle'>- Backend -</span>"
                      "</div>"
                      "<div class='menu'>"
                      "<a href='index.html'>Settings</a>"
                      "</div>"
                      "</div>"
                      "<div class='right'>"
                      "<div class='content'>";

const String pend = "</div>"
                    "</div>"
                    "</body>"
                    "</html>";

String last_error = "";

// ONLY READ THE FIRST LINE UNTIL NEW LINE !!!!!
String read_file(const char* _file, String _default = "")
{
    File f = SPIFFS.open(_file, "r");
    String tmp = _default;
    if (!f) {
        last_error = "open filesystem file_ntp_server failed";
    }
    else {
        tmp = f.readStringUntil('\n');
        last_error = "read from FS:" + String(_file) + " " + tmp;
    }
    return tmp;
}

void restore_eeprom_values()
{
    ntp_server_url = read_file(file_ntp_server,DEFAULT_NTP_SERVER);
    timezone = read_file(file_timezone, String(DEFAULT_TIMEZONE)).toInt();
    sync_mode = read_file(file_syncmode, "1").toInt();
}

bool write_file(const char* _file, String _content)
{
    File f = SPIFFS.open(_file, "w");
    if (!f) {
        last_error = "Oeffnen der Datei fehlgeschlagen";
        return -1;
    }
    f.print(_content);
    f.close();
    return 0;
}

void save_values_to_eeprom()
{
    write_file(file_ntp_server, ntp_server_url);
    write_file(file_syncmode, String(sync_mode));
    write_file(file_timezone, String(timezone));
}


void send_time_to_clock(){
  Serial.flush();
  delay(100);


int tmph = timeClient.getHours();
if((tmph+timezone)>23){tmph =tmph+timezone-24;}
else if((tmph+timezone)<0){tmph = tmph+timezone+24;}else{
  tmph = tmph+timezone;}

            Serial.println("_st_" + String(tmph) + "_" + String(timeClient.getMinutes()) + "_");
            last_error = "_st_" + String(tmph) + "_" + String(timeClient.getMinutes()) + "_";
            delay(100);
  }
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

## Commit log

2018-12-12 added 3d files
    [pipe_holder_bottom.stl, pipe_holder_top.stl, tube_pcb_mounting_bracket.stl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]
2018-12-12 added drill plan
2019-04-08 adding wifi extention arduino code
2019-04-08 added wifi gerber
2019-04-10 added i2c slave first test
2019-04-10 add i2c display
